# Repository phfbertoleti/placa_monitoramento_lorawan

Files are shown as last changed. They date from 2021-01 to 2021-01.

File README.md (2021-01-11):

# Placa - Monitoramento LoRaWAN / manutenção preventiva

Este é o repositório oficial da placa "Monitamento LoRaWAN" / placa "manutenção preventiva". Esta placa é um projeto open-source de minha autoria para monitamento de variáveis via LoRaWAN e para uso em algumas aplicações de manutenção preventiva. Este projeto faz uso do módulo Heltec wifi LoRa V1 (com conectividades LoRa/LoRaWAN, BLE e wi-fi).

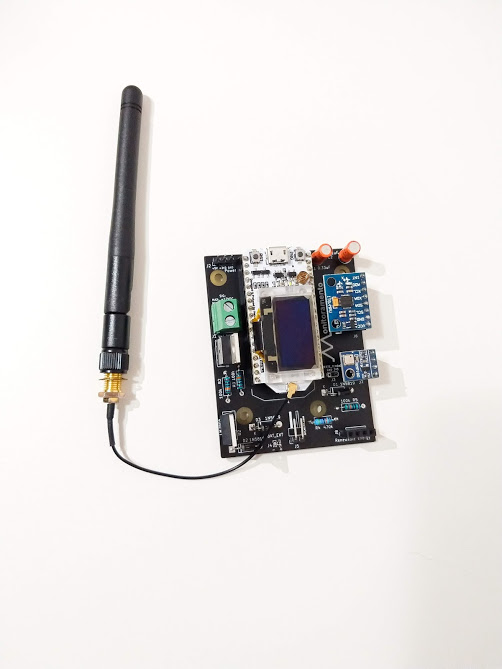
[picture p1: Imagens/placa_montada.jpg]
Placa monitoramento LoRaWAN / manutenção preventiva


## Princípio de funcionamento

Essa placa tem objetivo de facilitar o desenvolvimento de protótipos em Internet das Coisas, principalmente para aqueles focados em monitoramento remoto e manutenção preventiva. Para facilitar a montagem e uso, o Heltec wifi LoRa V1 e os módulos sensores são conectados em soquetes / barras de pinos do tipo fêmea. 
A placa suporta os seguintes módulos sensores:

* Módulo MPU6050
* Módulo BMP180

Ainda, a placa possui entrada digital (3.3V - 12V), que pode ser usada também para entradas pulsadas.

Quanto à alimentação, essa placa permite:
- Ser alimentada com bateria (LiPo ou Li-Ion, de 1 célula), com recarga por energias renováveis (7V - 12V), até 3 fontes diferentes de energias renováveis, desde que na mesma tensão.
- Ser alimentada por fonte 5V/2A via conector micro-USB.

Para facilitar o uso, a placa possui furação idêntica ao Arduino UNO. Dessa forma, fica mais simples projetar cases ou utilizar cases já fabricados.

## Funcionalidades

Esta placa, usada juntamente com um módulo Heltec wifi LoRa V1 e os sensores que a placa suporta, compreende as seguintes funcionaliades:
 
* Conectividades wifi, Bluetooth (BLE e clássico), LoRa e LoRaWAN.
* Medição de temperatura
* Medição de pressão barométrica
* Medição de aceleração (3 eixos)
* Giroscópio (3 eixos)
* Exibição de textos e imagens em display OLED 0.96" (azul)
* Recarga de bateria via energias renováveis

## O que está disponivel neste repositório?

Resposta curta: 100% do projeto. Ou seja:

* Projeto completo de hardware (feito no KiCad 5.1.5)
* Arquivos gerber, já nos padrões para fabricação exigidos pela JLCPCB (www.jlcpcb.com)
* Softwares de exemplo (todos feitos na Arduino IDE, fazendo uso de bibliotecas populares e consagradas)
* Lista de materiais (BOM)

Para ver a BOM interativa, [clique aqui](https://htmlpreview.github.io/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)

## Desejo contribuir com novas funcionalidades ou correções. Sou bem vindo?

Claro. Sinta-se a vontade para contribuir com o projeto. Toda melhoria é bem vinda!

## Gostei do seu trabalho. Onde consigo mais coisas publicadas por você?

Visite meu [site pessoal](http://www.pedrobertoleti.com.br) para ter acesso a quase tudo que publico no Brasil e exterior.

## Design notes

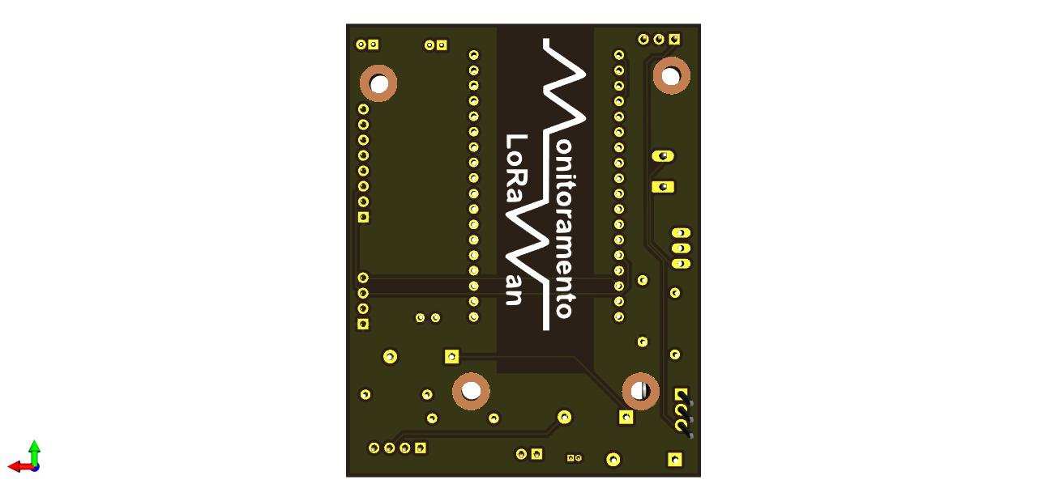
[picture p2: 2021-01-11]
Imagens/placa_manutencao_preventiva_bottom.jpg

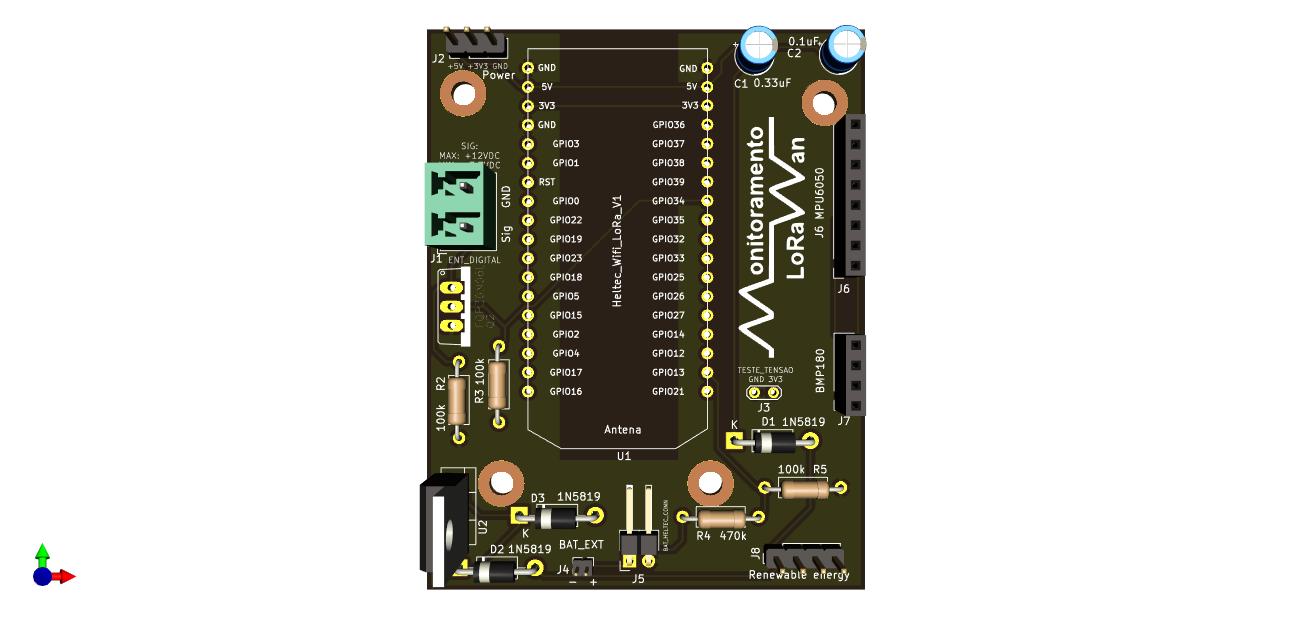
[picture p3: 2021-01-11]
Imagens/placa_manutencao_preventiva_top.jpg

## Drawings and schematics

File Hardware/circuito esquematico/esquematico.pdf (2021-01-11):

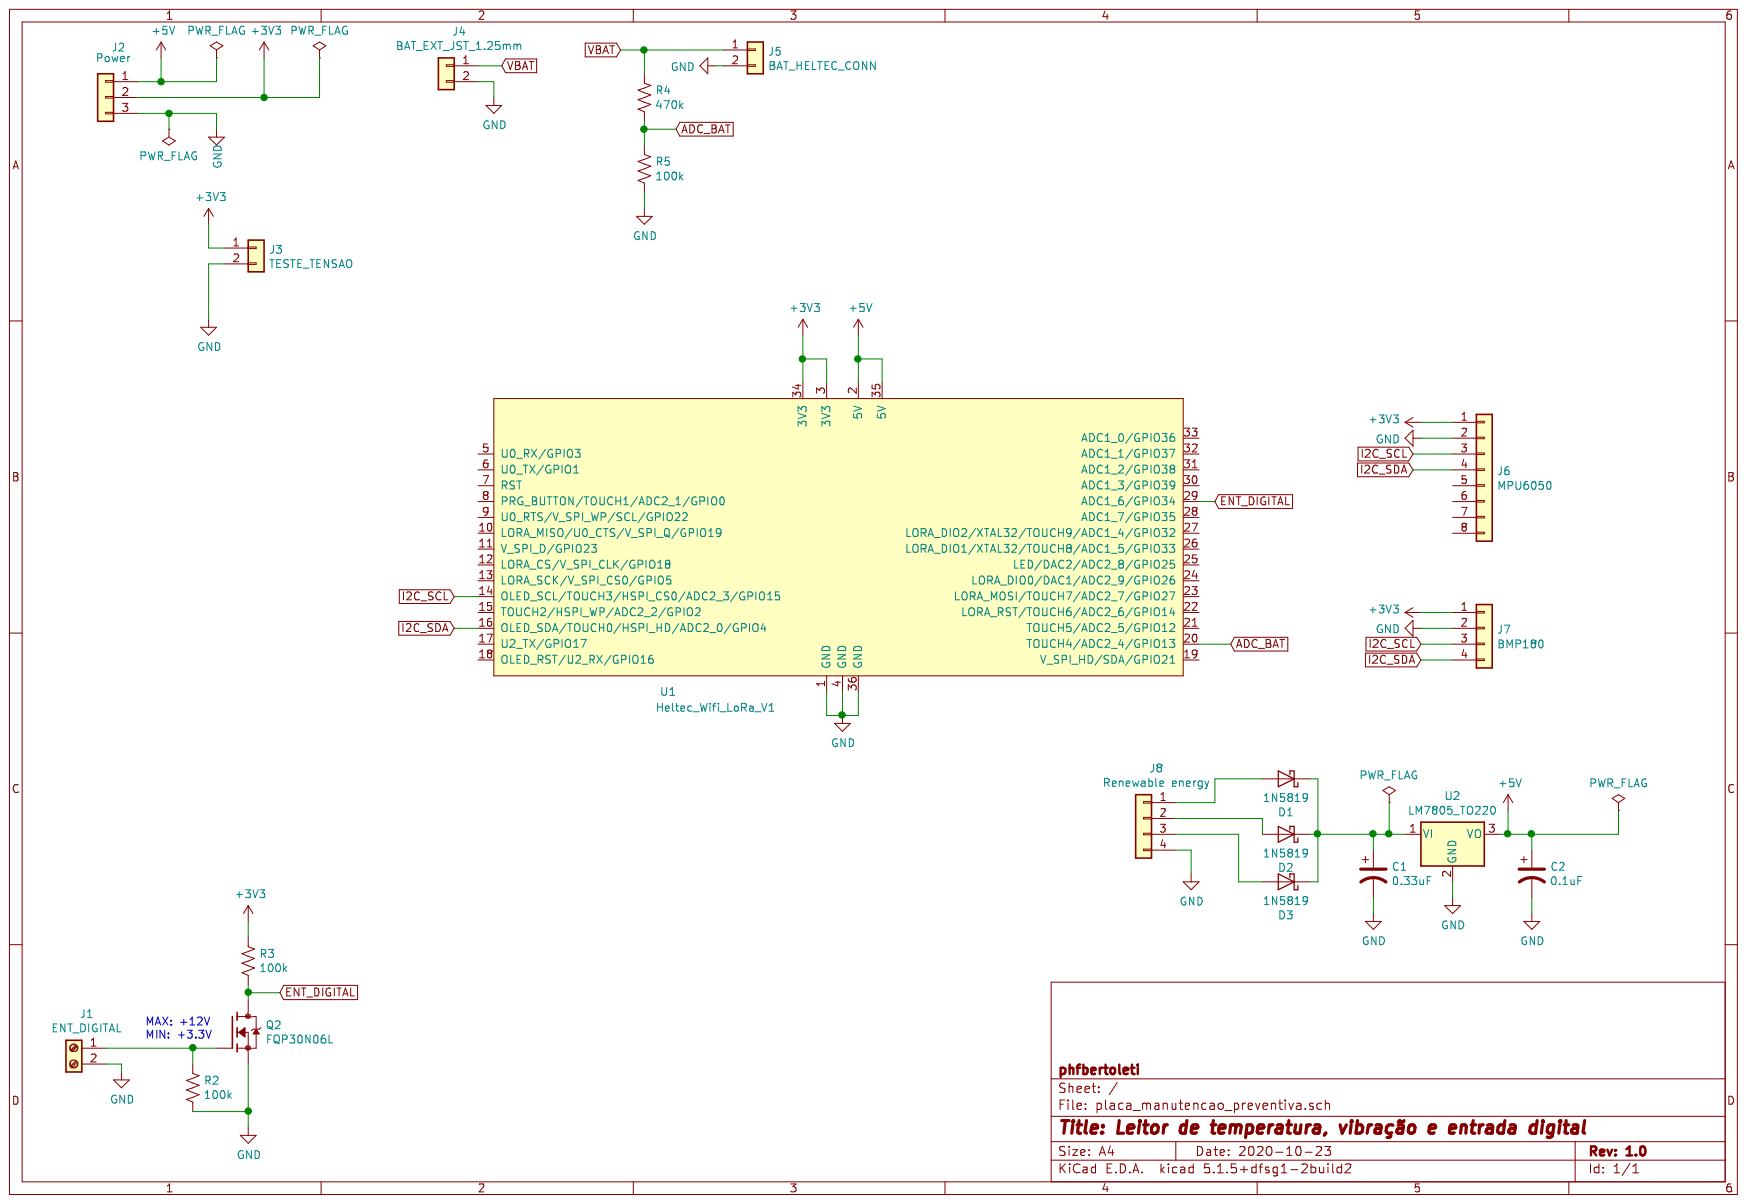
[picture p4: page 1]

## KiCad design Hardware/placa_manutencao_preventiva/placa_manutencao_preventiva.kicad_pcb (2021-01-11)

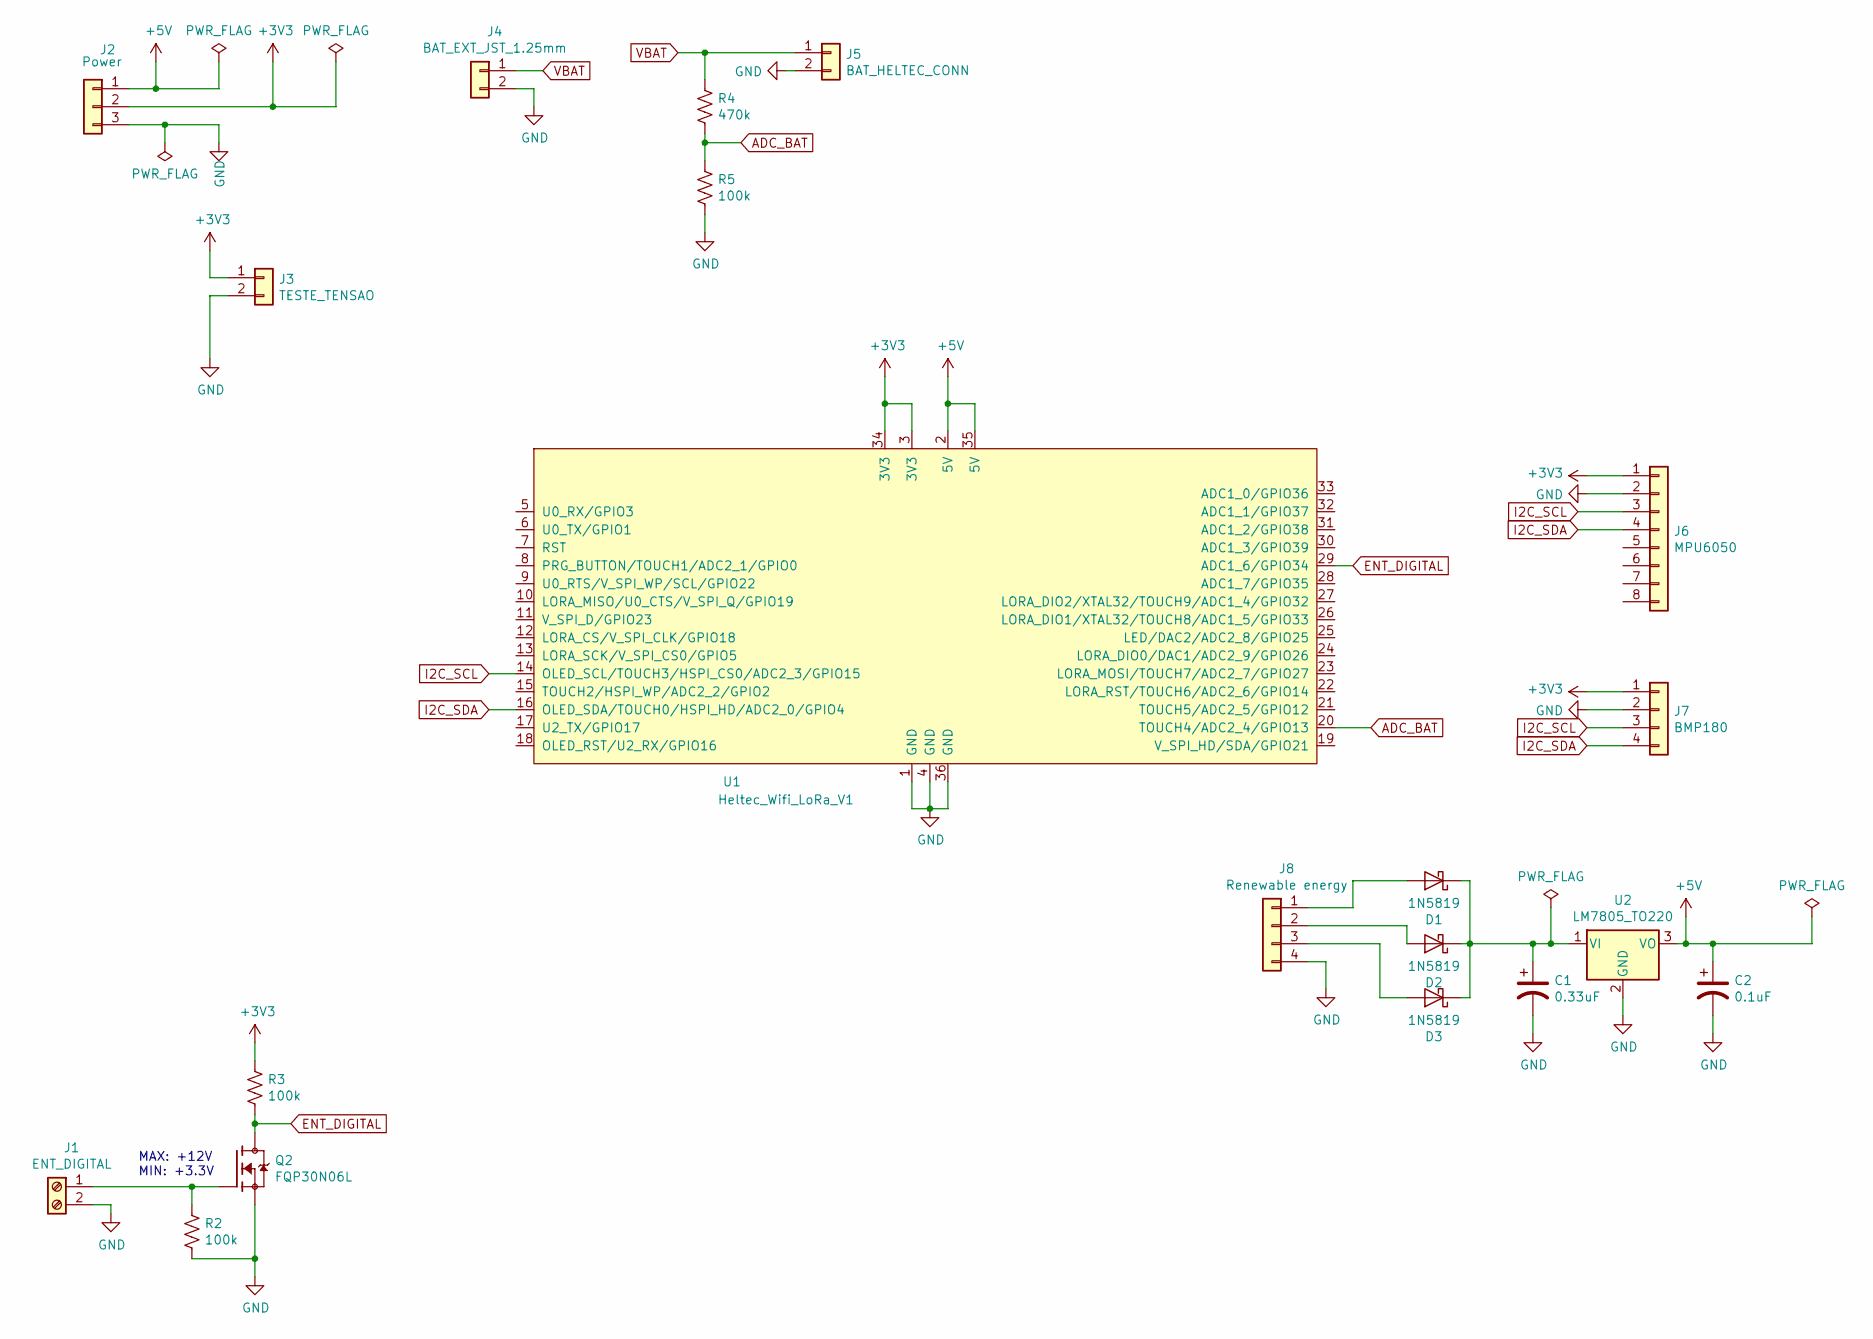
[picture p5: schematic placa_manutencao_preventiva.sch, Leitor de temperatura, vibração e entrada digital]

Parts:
C1: 0.33uF; CP_Radial_D5.0mm_P2.00mm
C2: 0.1uF; CP_Radial_D5.0mm_P2.00mm
D1, D2, D3: 1N5819; D_DO-41_SOD81_P10.16mm_Horizontal
J1: ENT_DIGITAL; PhoenixContact_MCV_1,5_2-G-5.08_1x02_P5.08mm_Vertical
J2: Power; PinHeader_1x03_P2.54mm_Vertical
J3: TESTE_TENSAO; TestPoint_2Pads_Pitch2.54mm_Drill0.8mm
J4: BAT_EXT_JST_1.25mm; PinHeader_1x02_P1.27mm_Vertical
J5: BAT_HELTEC_CONN; PinHeader_1x02_P2.54mm_Horizontal
J6: MPU6050; PinSocket_1x08_P2.54mm_Vertical
J7: BMP180; PinSocket_1x04_P2.54mm_Vertical
J8: Renewable energy; PinHeader_1x04_P2.54mm_Vertical
Q2: FQP30N06L; TO220V
R2, R3, R5: 100k; R_Axial_DIN0207_L6.3mm_D2.5mm_P10.16mm_Horizontal
R4: 470k; R_Axial_DIN0207_L6.3mm_D2.5mm_P10.16mm_Horizontal
U1: Heltec_Wifi_LoRa_V1; Heltec_WiFi_LoRa_V1
U2: LM7805_TO220; TO-220-3_Vertical

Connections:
+3V3: J2.2, J3.1, J6.1, J7.1, R3.1, U1.3 (3V3), U1.34 (3V3)
+5V: C2.1, J2.1, U1.2 (5V), U1.35 (5V), U2.3 (VO)
ADC_BAT: R4.2, R5.1, U1.20 (TOUCH4/ADC2_4/GPIO13)
ENT_DIGITAL: Q2.2, R3.2, U1.29 (ADC1_6/GPIO34)
GND: C1.2, C2.2, J1.2, J2.3, J3.2, J4.2, J5.2, J6.2, J7.2, J8.4, Q2.3, R2.2, R5.2, U1.1 (GND), U1.4 (GND), U1.36 (GND), U2.2 (GND)
I2C_SCL: J6.3, J7.3, U1.14 (OLED_SCL/TOUCH3/HSPI_CS0/ADC2_3/GPIO15)
I2C_SDA: J6.4, J7.4, U1.16 (OLED_SDA/TOUCH0/HSPI_HD/ADC2_0/GPIO4)
unnamed: C1.1, D1.1 (K), D2.1 (K), D3.1 (K), U2.1 (VI)
unnamed: D1.2 (A), J8.1
unnamed: D2.2 (A), J8.2
unnamed: D3.2 (A), J8.3
unnamed: J1.1, Q2.1, R2.1
VBAT: J4.1, J5.1, R4.1

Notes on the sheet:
MAX: +12V MIN: +3.3V

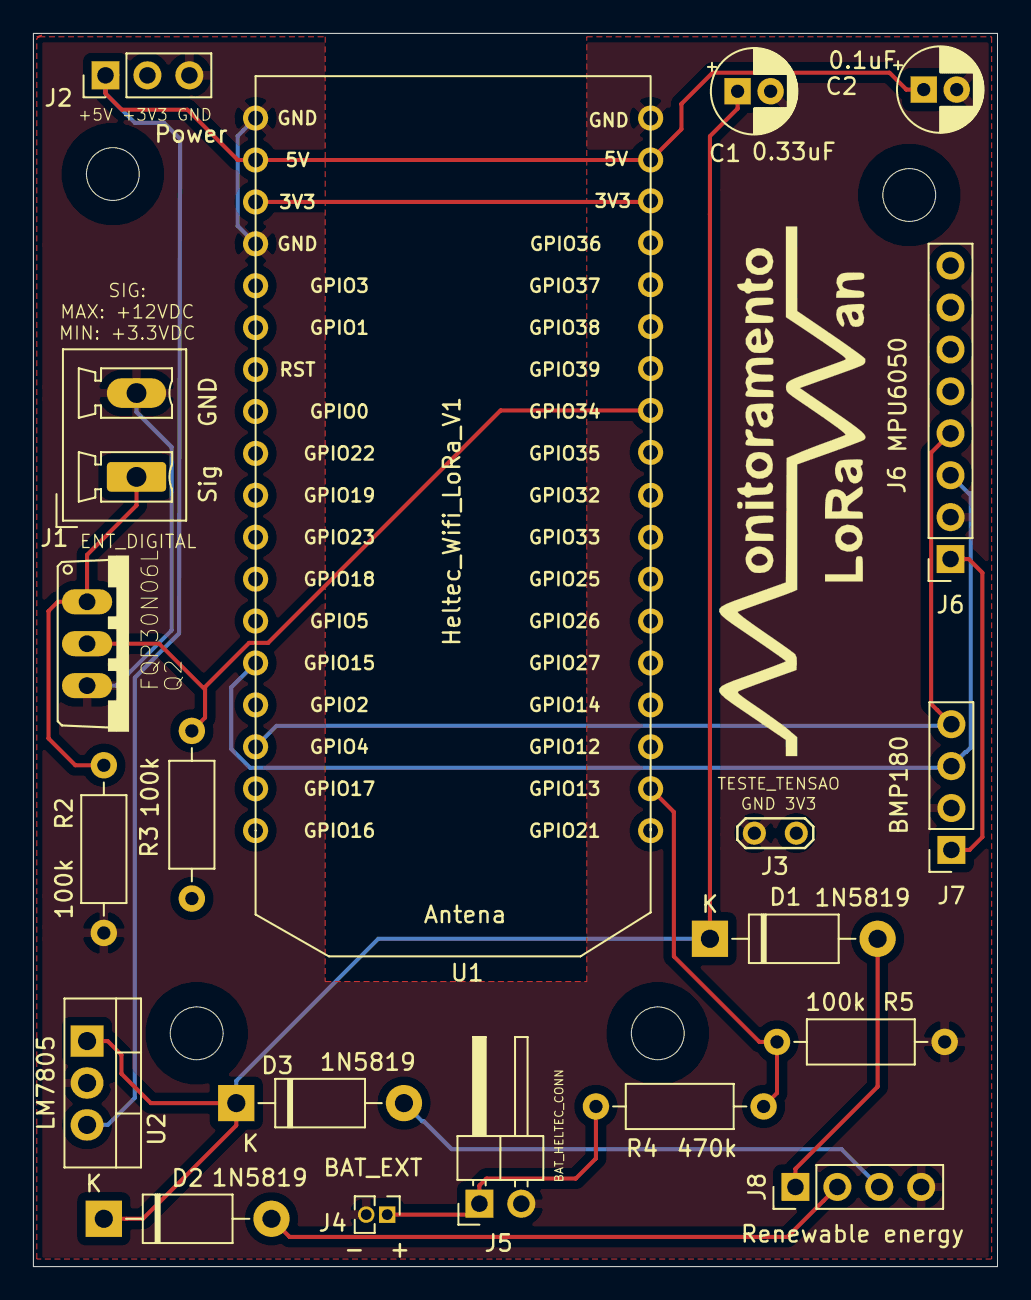
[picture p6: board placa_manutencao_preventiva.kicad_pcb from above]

Board: 2 copper layers, 58.4 x 74.7 mm, 21 parts (0 on the bottom side), 13 nets.

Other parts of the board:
 : Arduino_UNO_R3_OnlyMountingHoles

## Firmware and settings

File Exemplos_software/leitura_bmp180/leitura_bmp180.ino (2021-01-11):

#include <Adafruit_BMP085.h>
#include <Adafruit_GFX.h>
#include <Adafruit_SSD1306.h>

/* Definições - OLED */
#define OLED_CLEAR_LINE      "                     "
#define OLED_LINE_MAX_SIZE   21
#define OLED_SDA_PIN         4
#define OLED_SCL_PIN         15
#define OLED_ADDRESS         0x3C
#define OLED_RESET           16 
#define OLED_SCREEN_HEIGHT   64
#define OLED_SCREEN_WIDTH    128
#define OLED_LINHA_1         0
#define OLED_LINHA_2         10
#define OLED_LINHA_3         20
#define OLED_LINHA_4         30
#define OLED_LINHA_5         40
#define OLED_LINHA_6         50

/* Figura - termometro */
const unsigned char termometro [] PROGMEM = {
  0xff, 0xf0, 0xfe, 0x0f, 0xff, 0xff, 0xff, 0xff, 0xff, 0xff, 0xff, 0xff, 0xff, 0xff, 0xff, 0xff, 
  0xff, 0xe3, 0xff, 0xc3, 0xff, 0xff, 0xff, 0xff, 0xff, 0xff, 0xff, 0xff, 0xff, 0xff, 0xff, 0xff, 
  0xff, 0xcf, 0x01, 0xf3, 0xff, 0xff, 0xff, 0xff, 0xff, 0xff, 0xff, 0xff, 0xff, 0xff, 0xff, 0xff, 
  0xff, 0x9c, 0x00, 0x39, 0xc7, 0xe1, 0xff, 0xff, 0xff, 0xff, 0xff, 0xff, 0xff, 0xff, 0xff, 0xff, 
  0xff, 0x9c, 0x00, 0x3d, 0xc3, 0x80, 0xff, 0xff, 0xff, 0xff, 0xff, 0xff, 0xff, 0xff, 0xff, 0xff, 
  0xff, 0x9c, 0x00, 0x3d, 0x99, 0x1c, 0x7f, 0xff, 0xff, 0xff, 0xff, 0xff, 0xff, 0xff, 0xff, 0xff, 
  0xff, 0x9c, 0x00, 0x3d, 0x99, 0x3e, 0x7f, 0xff, 0xff, 0xff, 0xff, 0xff, 0xff, 0xff, 0xff, 0xff, 
  0xff, 0x9c, 0x00, 0x1d, 0xc3, 0x3f, 0xff, 0xff, 0xff, 0xff, 0xff, 0xff, 0xff, 0xff, 0xff, 0xff, 
  0xff, 0x9c, 0x3f, 0xfd, 0xc7, 0x3f, 0xff, 0xff, 0xff, 0xff, 0xff, 0xff, 0xff, 0xff, 0xff, 0xff, 
  0xff, 0x9c, 0x00, 0x1d, 0xff, 0x3f, 0xff, 0xff, 0xff, 0xff, 0xff, 0xff, 0xff, 0xff, 0xff, 0xff, 
  0xff, 0x9c, 0x00, 0x1d, 0xff, 0x3f, 0xff, 0xff, 0xff, 0xff, 0xff, 0xff, 0xff, 0xff, 0xff, 0xff, 
  0xff, 0x9c, 0x00, 0x1d, 0xff, 0x3e, 0x7f, 0xff, 0xff, 0xff, 0xff, 0xff, 0xff, 0xff, 0xff, 0xff, 
  0xff, 0x9c, 0x00, 0x1d, 0xff, 0x1c, 0x7f, 0xff, 0xff, 0xff, 0xff, 0xff, 0xff, 0xff, 0xff, 0xff, 
  0xff, 0x9c, 0x00, 0x1d, 0xff, 0x80, 0xff, 0xff, 0xff, 0xff, 0xff, 0xff, 0xff, 0xff, 0xff, 0xff, 
  0xff, 0x9c, 0x00, 0x1d, 0xff, 0xc1, 0xff, 0xff, 0xff, 0xff, 0xff, 0xff, 0xff, 0xff, 0xff, 0xff, 
  0xff, 0x9c, 0x00, 0x1d, 0xff, 0xff, 0xff, 0xff, 0xff, 0xff, 0xff, 0xff, 0xff, 0xff, 0xff, 0xff, 
  0xff, 0x9c, 0x7f, 0xfd, 0xff, 0xff, 0xff, 0xff, 0xff, 0xff, 0xff, 0xff, 0xff, 0xff, 0xff, 0xff, 
  0xff, 0x9c, 0x00, 0x1d, 0xff, 0xff, 0xff, 0xff, 0xff, 0xff, 0xff, 0xff, 0xff, 0xff, 0xff, 0xff, 
  0xff, 0x9c, 0x00, 0x1d, 0xff, 0xff, 0xff, 0xff, 0xff, 0xff, 0xff, 0xff, 0xff, 0xff, 0xff, 0xff, 
  0xff, 0x9c, 0x00, 0x1d, 0xff, 0xff, 0xff, 0xff, 0xff, 0xff, 0xff, 0xff, 0xff, 0xff, 0xff, 0xff, 
  0xff, 0x9c, 0x00, 0x1d, 0xff, 0xff, 0xff, 0xff, 0xff, 0xff, 0xff, 0xff, 0xff, 0xff, 0xff, 0xff, 
  0xff, 0x9c, 0x7f, 0xfd, 0xff, 0xff, 0xff, 0xff, 0xff, 0xff, 0xff, 0xff, 0xff, 0xff, 0xff, 0xff, 
  0xff, 0x1c, 0x00, 0x1d, 0xff, 0xff, 0xff, 0xff, 0xff, 0xff, 0xff, 0xff, 0xff, 0xff, 0xff, 0xff, 
  0xff, 0x1c, 0x00, 0x1d, 0xff, 0xff, 0xff, 0xff, 0xff, 0xff, 0xff, 0xff, 0xff, 0xff, 0xff, 0xff, 
  0xff, 0x1c, 0x00, 0x1d, 0xff, 0xff, 0xff, 0xff, 0xff, 0xff, 0xff, 0xff, 0xff, 0xff, 0xff, 0xff, 
  0xff, 0x1c, 0x00, 0x1d, 0xff, 0xff, 0xff, 0xff, 0xff, 0xff, 0xff, 0xff, 0xff, 0xff, 0xff, 0xff, 
  0xff, 0x1c, 0x00, 0x1d, 0xff, 0xff, 0xff, 0xff, 0xff, 0xff, 0xff, 0xff, 0xff, 0xff, 0xff, 0xff, 
  0xff, 0x1c, 0x00, 0x1d, 0xff, 0xff, 0xff, 0xff, 0xff, 0xff, 0xff, 0xff, 0xff, 0xff, 0xff, 0xff, 
  0xff, 0x1c, 0x1f, 0xfd, 0xff, 0xff, 0xff, 0xff, 0xff, 0xff, 0xff, 0xff, 0xff, 0xff, 0xff, 0xff, 
  0xff, 0x1c, 0x00, 0x1d, 0xff, 0xff, 0xff, 0xff, 0xff, 0xff, 0xff, 0xff, 0xff, 0xff, 0xff, 0xff, 
  0xff, 0x1c, 0x00, 0x1d, 0xff, 0xff, 0xff, 0xff, 0xff, 0xff, 0xff, 0xff, 0xff, 0xff, 0xff, 0xff, 
  0xff, 0x1c, 0x00, 0x1d, 0xff, 0xff, 0xff, 0xff, 0xff, 0xff, 0xff, 0xff, 0xff, 0xff, 0xff, 0xff, 
  0xff, 0x1c, 0x00, 0x1d, 0xff, 0xff, 0xff, 0xff, 0xff, 0xff, 0xff, 0xff, 0xff, 0xff, 0xff, 0xff, 
  0xff, 0x1c, 0x00, 0x1d, 0xff, 0xff, 0xff, 0xff, 0xff, 0xff, 0xff, 0xff, 0xff, 0xff, 0xff, 0xff, 
  0xff, 0x1c, 0x00, 0x1d, 0xff, 0xff, 0xff, 0xff, 0xff, 0xff, 0xff, 0xff, 0xff, 0xff, 0xff, 0xff, 
  0xff, 0x1c, 0x00, 0x1d, 0xff, 0xff, 0xff, 0xff, 0xff, 0xff, 0xff, 0xff, 0xff, 0xff, 0xff, 0xff, 
  0xff, 0x1c, 0x00, 0x1d, 0xff, 0xff, 0xff, 0xff, 0xff, 0xff, 0xff, 0xff, 0xff, 0xff, 0xff, 0xff, 
  0xff, 0x1c, 0x00, 0x1d, 0xff, 0xff, 0xff, 0xff, 0xff, 0xff, 0xff, 0xff, 0xff, 0xff, 0xff, 0xff, 
  0xff, 0x1c, 0x00, 0x1d, 0xff, 0xff, 0xff, 0xff, 0xff, 0xff, 0xff, 0xff, 0xff, 0xff, 0xff, 0xff, 
  0xff, 0x1c, 0x00, 0x1d, 0xff, 0xff, 0xff, 0xff, 0xff, 0xff, 0xff, 0xff, 0xff, 0xff, 0xff, 0xff, 
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
};


/* Variaveis globais */
char linha_str[OLED_LINE_MAX_SIZE];
int estado_led;
Adafruit_BMP085 bmp180;
Adafruit_SSD1306 display(OLED_SCREEN_WIDTH, 
                         OLED_SCREEN_HEIGHT, 
                         &Wire, 
                         OLED_RESET, 
                         100000UL, 
                         100000UL);

/* Prototipos */
void init_bmp180(void);
float le_temperatura(void);
float le_pressao(void);

/*
 * Implementações
 */

/* Função: inicializa sensor BMP180
 * Parâmetros: nenhum
 * Retorno: nenhum
 */
void init_bmp180(void)
{
    if (!bmp180.begin()) 
    {
        Serial.println("[BMP180] Sensor nao encontrado.");
        while (1) 
        {
            delay(1);  
        }
    }
}

/* Função: le temperatura (do sensor BMP180)
 * Parâmetros: nenhum
 * Retorno:  temperatura lida
 */
float le_temperatura(void)
{   
    return bmp180.readTemperature();
}

/* Função: le sensor de pressão barométrica
 * Parâmetros: nenhum
 * Retorno:  pressao lida
 */
float le_pressao(void)
{
    return bmp180.readPressure();
}


void setup() 
{
    Serial.begin(115200);
        
    /* Inicializa I²C (para comunicação com OLED e BMP180)*/
    Wire.begin(OLED_SDA_PIN, OLED_SCL_PIN);

  /* Inicializa display */
    if(!display.begin(SSD1306_SWITCHCAPVCC, OLED_ADDRESS)) 
    { 
        Serial.println("[ERRO] não foi possivel inicializar display. O ESP32 será reiniciado em 1s...");
        delay(1000);
        ESP.restart();
    }
    else
    {
        Serial.println("Display inicializado.");
        display.clearDisplay();
        display.setTextColor(WHITE);
        display.setTextSize(1);
        display.setCursor(0,OLED_LINHA_1);
        display.println("   Kit wifi Heltec");
        display.setCursor(0,OLED_LINHA_2);
        display.println("        LoRa V1");
        display.setCursor(0,OLED_LINHA_3);
        display.println("_____________________");
        display.setCursor(0,OLED_LINHA_5);
        display.println("Pedro Bertoleti");
        display.setCursor(0,OLED_LINHA_6);
        display.println("pedrobertoleti.com.br");
        display.display();
        delay(500);
    }

    /* Inicializa BMP180 */
    init_bmp180();
}

void loop() 
{
    float pressao_kPa, temperatura;
    
    pressao_kPa = le_pressao()/1000.0;
    temperatura = le_temperatura();

    display.clearDisplay();
    display.drawBitmap(0, 0, termometro, 128, 64, 1);
    display.setTextColor(BLACK);
    display.setTextSize(2);
    display.setCursor(59,OLED_LINHA_2);
    sprintf(linha_str,"%.0fC", temperatura);
    display.println(linha_str);
    display.setCursor(40,OLED_LINHA_5);
    sprintf(linha_str,"%.1fkPa", pressao_kPa);
    display.println(linha_str);
    display.display();   

    /* Aguarda 1 segundo para próxima leitura */
    delay(1000);
}

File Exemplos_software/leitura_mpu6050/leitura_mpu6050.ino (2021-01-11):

#include <Adafruit_GFX.h>
#include <Adafruit_SSD1306.h>
#include <Adafruit_MPU6050.h>
#include <Adafruit_Sensor.h>

/* Definições - OLED */
#define OLED_CLEAR_LINE      "                     "
#define OLED_LINE_MAX_SIZE   21
#define OLED_SDA_PIN         4
#define OLED_SCL_PIN         15
#define OLED_ADDRESS         0x3C
#define OLED_RESET           16 
#define OLED_SCREEN_HEIGHT   64
#define OLED_SCREEN_WIDTH    128
#define OLED_LINHA_1         0
#define OLED_LINHA_2         10
#define OLED_LINHA_3         20
#define OLED_LINHA_4         30
#define OLED_LINHA_5         40
#define OLED_LINHA_6         50

/* Definição - aceleração da gravidade */
#define VALOR_GRAVIDADE    9.80665  // m/s²

/* Definição - número de leituras para calibração da IMU */
#define NUM_LEITURAS_CALIBRACAO    100

/* Variaveis globais */
char linha_str[OLED_LINE_MAX_SIZE];
int estado_led;
float offset_ax = 0.0;
float offset_ay = 0.0;
float offset_az = 0.0;
float offset_gx = 0.0;
float offset_gy = 0.0;
float offset_gz = 0.0;
float ax, ay, az, gx, gy, gz;
Adafruit_MPU6050 mpu;
Adafruit_SSD1306 display(OLED_SCREEN_WIDTH, 
                         OLED_SCREEN_HEIGHT, 
                         &Wire, 
                         OLED_RESET, 
                         100000UL, 
                         100000UL);

/* Protótipos */
void calibra_acc_giroscopio(void); 
                         
/*
 * Implementações
 */
/* Função: faz calibração do acelerometro e giroscopio
 * Parametros: nenhum 
 * Retorno: nenhum
 */
void calibra_acc_giroscopio(void)
{
    int i;
    sensors_event_t a, g, temp;
    float soma_ax = 0;
    float soma_ay = 0;
    float soma_az = 0;
    float soma_gx = 0;
    float soma_gy = 0;
    float soma_gz = 0;

    for (i=0; i<NUM_LEITURAS_CALIBRACAO; i++)
    {
        mpu.getEvent(&a, &g, &temp);
        
        soma_ax = soma_ax + a.acceleration.x;
        soma_ay = soma_ay + a.acceleration.y;
        soma_az = soma_az + a.acceleration.z;

        soma_gx = soma_gx + g.gyro.x;
        soma_gy = soma_gy + g.gyro.y;
        soma_gz = soma_gz + g.gyro.z;        
    }

    offset_ax = (float)soma_ax/NUM_LEITURAS_CALIBRACAO;
    offset_ay = (float)soma_ay/NUM_LEITURAS_CALIBRACAO;
    offset_az = (float)(soma_az / NUM_LEITURAS_CALIBRACAO) - VALOR_GRAVIDADE;

    offset_gx = soma_gx/NUM_LEITURAS_CALIBRACAO;
    offset_gy = soma_gy/NUM_LEITURAS_CALIBRACAO;
    offset_gz = soma_gz/NUM_LEITURAS_CALIBRACAO;    
}

void setup() 
{
    Serial.begin(115200);
      
    /* Inicializa I²C (para comunicação com OLED e MPU6050)*/
    Wire.begin(OLED_SDA_PIN, OLED_SCL_PIN);

    /* Inicializa MPU6050 */
    if (!mpu.begin()) 
    {
        Serial.println("ERRO: falha ao inicializar MPU6050. O ESP32 reiniciará em 1s...");
        delay(1000);
        ESP.restart();
    }
    else
    {
        /* Configura MPU6050 */
        mpu.setAccelerometerRange(MPU6050_RANGE_8_G);
        mpu.setGyroRange(MPU6050_RANGE_500_DEG);
        mpu.setFilterBandwidth(MPU6050_BAND_5_HZ);
        calibra_acc_giroscopio();
    }

    /* Inicializa display */
    if(!display.begin(SSD1306_SWITCHCAPVCC, OLED_ADDRESS)) 
    { 
        Serial.println("[ERRO] não foi possivel inicializar display. O NodeMCU será reiniciado em 1s...");
        delay(1000);
        ESP.restart();
    }
    else
    {
        Serial.println("Display inicializado.");
        display.clearDisplay();
        display.setTextColor(WHITE);
        display.setTextSize(1);
        display.setCursor(0,OLED_LINHA_1);
        display.println(" Monitoramento");
        display.setCursor(0,OLED_LINHA_2);
        display.println(" LoRaWAN");
        display.setCursor(0,OLED_LINHA_3);
        display.println("_____________________");
        display.setCursor(0,OLED_LINHA_5);
        display.println("Pedro Bertoleti");
        display.setCursor(0,OLED_LINHA_6);
        display.println("pedrobertoleti.com.br");
        display.display();
        delay(500);
    }
}

void loop() 
{    
    sensors_event_t a, g, temp;
    mpu.getEvent(&a, &g, &temp);
    

    /* Aplica offset às acelerações e componentes do giroscópios */
    ax = a.acceleration.x - offset_ax;
    ay = a.acceleration.y - offset_ay;
    az = a.acceleration.z - offset_az;
    gx = g.gyro.x - offset_gx;
    gy = g.gyro.y - offset_gy;
    gz = g.gyro.z - offset_gz;

    Serial.println(offset_az);
   
    display.clearDisplay();
    display.setTextColor(WHITE);
    display.setTextSize(1);
    display.setCursor(0,OLED_LINHA_1);
    display.println("   Dados - MPU6050");
    display.setCursor(0,OLED_LINHA_2);
    display.println("_____________________");
    display.setTextSize(1);
    display.setCursor(0,OLED_LINHA_3);
   
    sprintf(linha_str,"A: %.1f, %.1f, %.1f", ax, ay, az); 
    display.println(linha_str);

    display.setCursor(0,OLED_LINHA_4);
    display.println("m/s^2");
    
    display.setCursor(0,OLED_LINHA_5);
    sprintf(linha_str,"G: %.1f, %.1f, %.1f", gx, gy, gz); 
    display.println(linha_str);

    display.setCursor(0,OLED_LINHA_6);
    sprintf(linha_str,"rad/s  T: %.1fC", temp.temperature); 
    display.println(linha_str);
    display.display();

    /* Aguarda 1 segundo para próxima leitura */
    delay(1000);
}
